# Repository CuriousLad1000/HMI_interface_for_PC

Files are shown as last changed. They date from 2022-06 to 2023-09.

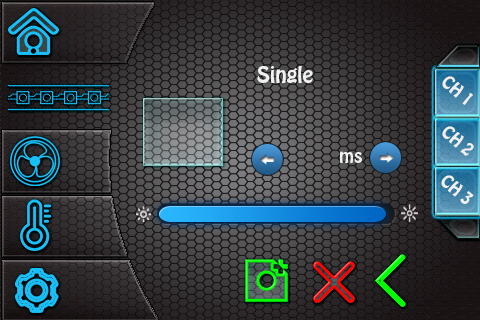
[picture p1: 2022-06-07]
UI Design files/LED/Single_Glow.png

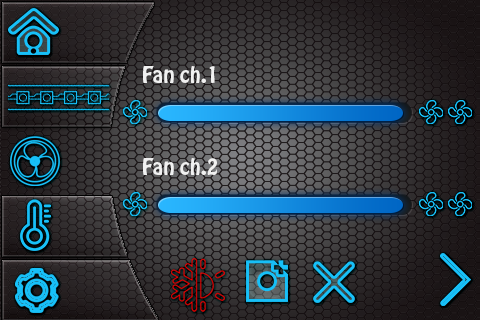
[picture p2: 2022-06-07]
UI Design files/FAN/Fan.png

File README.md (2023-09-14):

# HMI interface for PC

## Introduction

Personal Computers have become an integral part of our lives that even thinking about living without one would give us the feeling of falling back into stone age.

The idea behind this project was to build a smart Human Machine Interface for my personal computer. This project provided me with the opportunity of honing my skills while exploring various other domains. This project required technical expertise from different fields of technology including Electronics, Computer Science and Mechanical.

## Project Objective

The HMI interface will provide some advanced functionalities such as auto boot and shutdown, Automatic Temperature controller, vent controller, Lighting controller etc…

The project will involve some custom hardware designing, PCB fabrication, UX Designing, firmware programming, some mechanical designing and assembly using Rapid prototyping machines.

## Hardware/components used (not exhaustive list)

-   Arduino MEGA
-   3.5-inch Touch panel from Nextion
-   DC to DC Buck-Boost drivers
-   Mosfets (IRF510)
-   various passive components
-   Acryllic and MDF for casing and PC cabinet casing.
-   Laser cutter
-   CNC milling machine

## Software used

-   Arduino IDE (C/C++)
-   Nextion Editor to program touch panel.
-   Adobe Photoshop for UI designing.
-   Corel draw for Case, side panel and vents designing.
-   Cadsoft Eagle for PCB designing
-   Roland’s software and artcam for PCB fabrication (CNC milling).

##  Features offered

After completion, the HMI interface will have the following features.

-   Provide interactive system on/off switch
-   System Power on scheduler
-   Control the speed of fan based on conditions set.
    -   manual control of fan speed
    -   Automatic control based on the component’s temperature
-   Different Lighting modes for the system across multiple channels
    -   Rainbow
    -   Single color
    -   Fading on single color
    -   Rainbow cycle
    -   Color based on temperature
-   Display current temperature on multiple temperature gauges.
-   Provide settings for additional functionalities such as
    -   Open vents when system boots or based on the temperature -- servo control
    -   Enable power saver
    -   Enable/disable system status LED.
    -   Temperature channel assignment to various components.

<br/>

## Sample pictures (refer to wiki for more…)

<br/>

### HMI Interface

<br/>

**Home screen**

<p align="Center">
  
</p>

<p align="Center"> <i>"note: logo copyright belongs to Micro-Star INT'L CO., LTD" </i></p>

<br/>
<br/>

**Set Lighting modes**

<p align="Center">
  
</p>

<br/>
<br/>

**Temperature monitor**

<p align="Center">
  
</p>

<br/>
<br/>

## Device pics

<p align="Center">
  
</p>

<br/>
<br/>

**HMI Installed**

<p align="Center">
  
</p>

<br/>
<br/>

**HMI Operational**

<p align="Center">
  
</p>

<br/>
<br/>

> Check out wiki for more pics

<br/>
<br/>

### Video

<br/>
<br/>

**Device in action part-1**

<p align="Center">
  
</p>

<br/>
<br/>

**Device in action part-2**

<p align="Center">
  
</p>

<br/>

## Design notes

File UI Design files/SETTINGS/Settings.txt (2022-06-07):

setting for date and time

Open flaps when system boots  -- servo control

* flaps based on temperature -- Test basis

Enable power saver screen

Enable/disable system status LED. (Blue light on CPU cabinet)

Reset nextion display

-assign channels in settings to

-Controller
-CPU
-GPU
-HDD

-GPU
-HDD
-HDD Bay
-Motherboard

-HDD Bay
-Motherboard
-N-Bridge
-PSU

-N-Bridge
-PSU
-Radiator
-RAM

-PSU
-Radiator
-RAM
-Reservoir

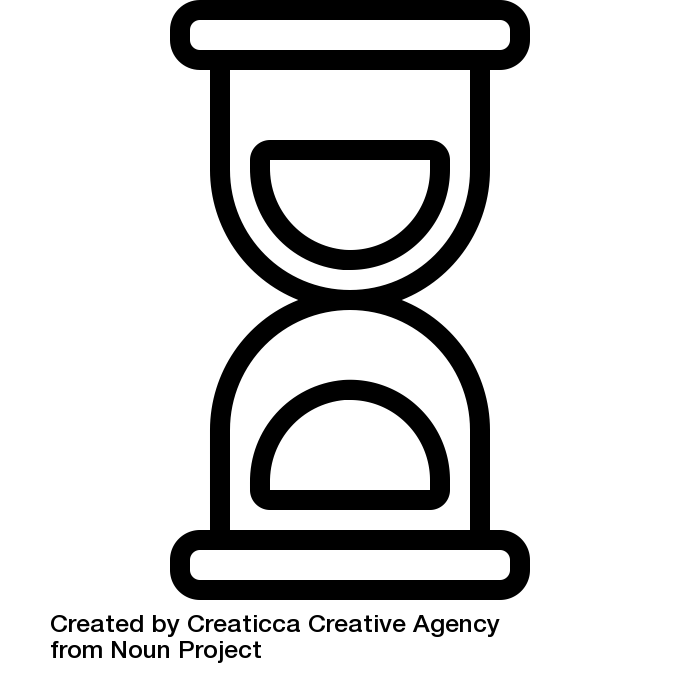
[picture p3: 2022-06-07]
UI Design files/HOME/noun_965902_cc.png

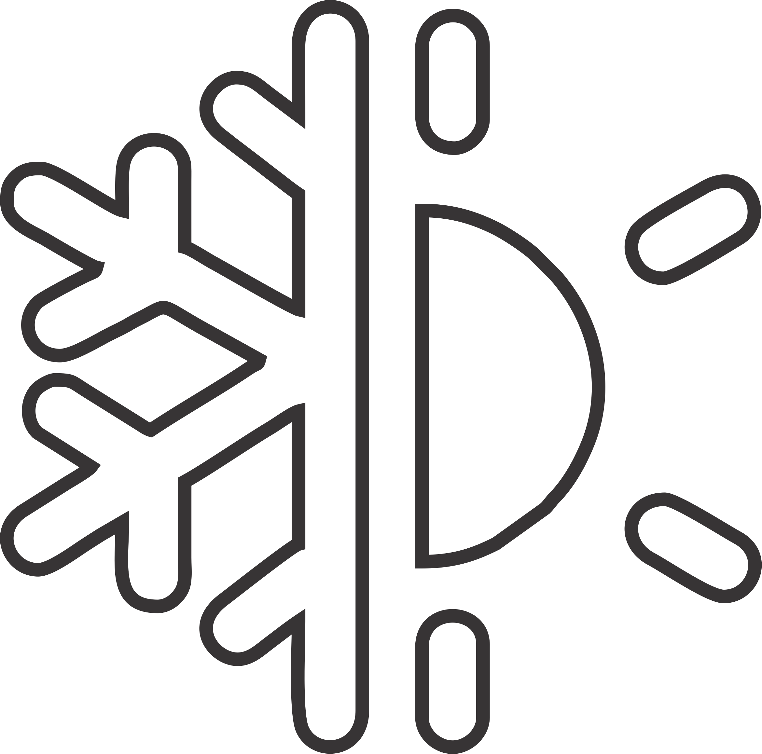
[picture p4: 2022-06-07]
UI Design files/FAN/tst2.png

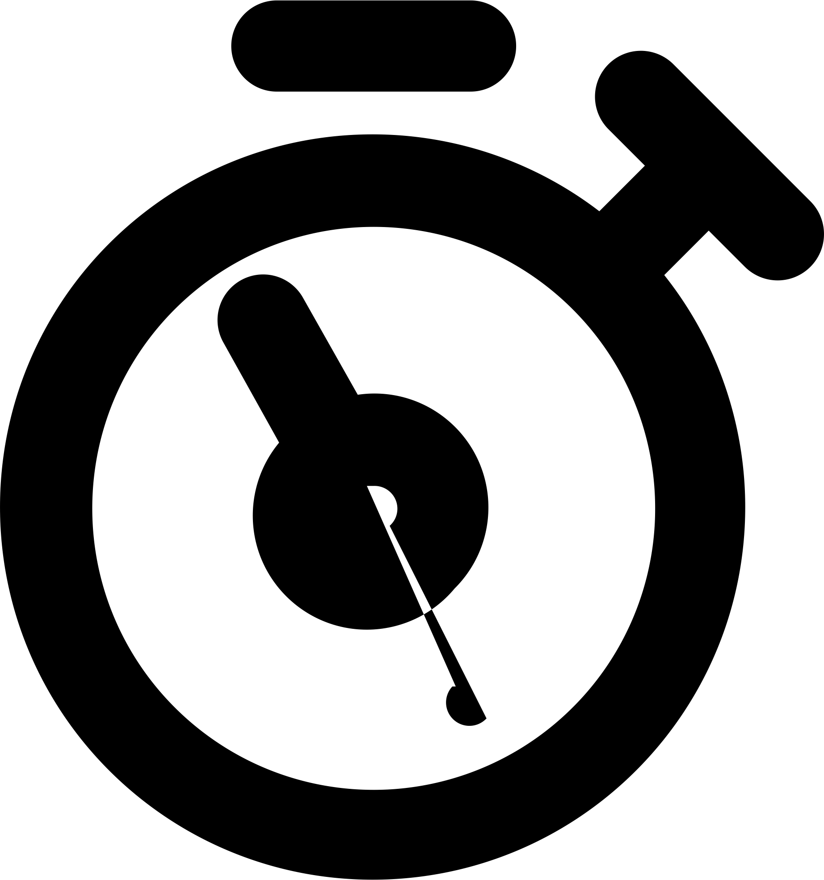
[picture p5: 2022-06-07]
UI Design files/HOME/Untitled-1.png

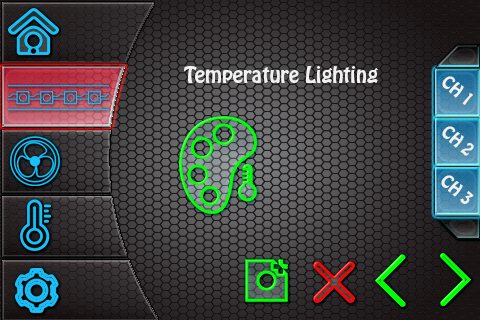
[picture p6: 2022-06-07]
UI Design files/LED/TempLight_Glow.png

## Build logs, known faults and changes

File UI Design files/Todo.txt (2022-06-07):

tst and prepare code for leds   --------------------- done

verify working of servo motor code    --------------- done

complie and run final test for the code  --------- done

add blink logo when shutdown command initiates

add power saver from nextion library and test it.  ----- done

create power switch jumper splitter  -- done

create connector harness for fans and LEDs

prepare sensors for installation

assemble servo vents and test it

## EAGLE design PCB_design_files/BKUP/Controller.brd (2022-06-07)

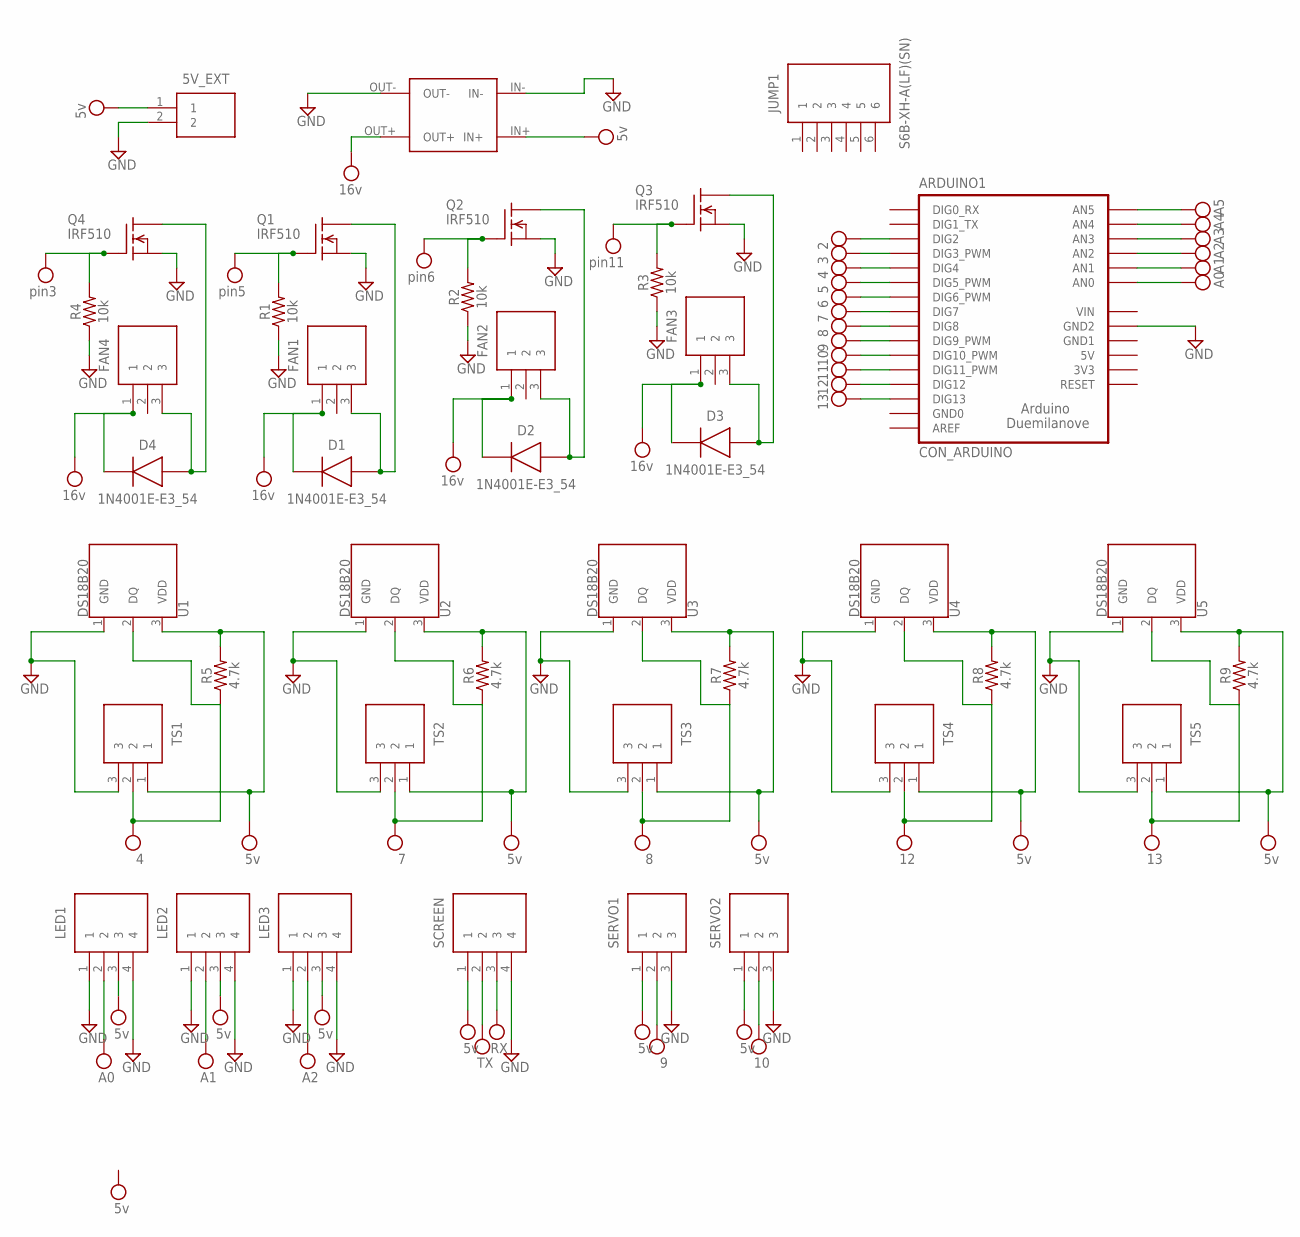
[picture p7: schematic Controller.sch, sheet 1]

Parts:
5V_EXT: S2B-XH-A(LF)(SN); SHDR2W80P0X250_1X2_740X575X700
ARDUINO1: CON_ARDUINO
D1, D2, D3, D4: 1N4001E-E3_54; DIOAD1405W86L465D235
FAN1, FAN2, FAN3, FAN4: S3B-XH-A(LF)(SN); SHDR3W80P0X250_1X3_990X610X700
JUMP1: S6B-XH-A(LF)(SN); SHDR6W64P0X250_1X6_1740X1155X7
LED1, LED2, LED3: S4B-XH-A(LF)(SN); SHDR4W64P0X250_1X4_1240X1155X7
Q1, Q2, Q3, Q4: IRF510; TO220
R1, R2, R3, R4: 10k; AXIAL-0.3
R5, R6, R7, R8, R9: 4.7k; AXIAL-0.3
SCREEN: S4B-XH-A(LF)(SN); SHDR4W64P0X250_1X4_1240X1155X7
SERVO1, SERVO2: S3B-XH-A(LF)(SN); SHDR3W80P0X250_1X3_990X610X700
TS1, TS2, TS3, TS4, TS5: S3B-XH-A(LF)(SN); SHDR3W80P0X250_1X3_990X610X700
U1, U2, U3, U4, U5: DS18B20; TO-92-AMMO
U$1: CN6009THROUGH_HOLE; CN6009

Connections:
5V_EXT: 5V_EXT.1, LED1.3, LED2.3, LED3.3, R5.P$2 (2), R6.P$2 (2), R7.P$2 (2), R8.P$2 (2), R9.P$2 (2), SCREEN.1, SERVO1.1, SERVO2.1, TS1.1, TS2.1, TS3.1, TS4.1, TS5.1, U1.3 (VDD), U2.3 (VDD), U3.3 (VDD), U4.3 (VDD), U5.3 (VDD), U$1.IN+; also elsewhere on the board
16V: D1.2 (K), D2.2 (K), D3.2 (K), D4.2 (K), FAN1.1, FAN2.1, FAN3.1, FAN4.1, U$1.OUT+; also elsewhere on the board
GND: 5V_EXT.2, ARDUINO1.GND2, LED1.1, LED1.4, LED2.1, LED2.4, LED3.1, LED3.4, Q1.3 (S), Q2.3 (S), Q3.3 (S), Q4.3 (S), R1.P$1 (1), R2.P$1 (1), R3.P$1 (1), R4.P$1 (1), SCREEN.4, SERVO1.3, SERVO2.3, TS1.3, TS2.3, TS3.3, TS4.3, TS5.3, U1.1 (GND), U2.1 (GND), U3.1 (GND), U4.1 (GND), U5.1 (GND), U$1.IN-, U$1.OUT-; also elsewhere on the board
unnamed: D2.1 (A), FAN2.3, Q2.2 (D)
unnamed: D3.1 (A), FAN3.3, Q3.2 (D)
unnamed: D1.1 (A), FAN1.3, Q1.2 (D)
unnamed: D4.1 (A), FAN4.3, Q4.2 (D)
PIN2: ARDUINO1.D_2 (DIG2)
PIN3: ARDUINO1.D_3 (DIG3_PWM), Q4.1 (G), R4.P$2 (2); also elsewhere on the board
PIN4: ARDUINO1.D_4 (DIG4), R5.P$1 (1), TS1.2, U1.2 (DQ)
PIN5: ARDUINO1.D_5 (DIG5_PWM), Q1.1 (G), R1.P$2 (2); also elsewhere on the board
PIN6: ARDUINO1.D_6 (DIG6_PWM), Q2.1 (G), R2.P$2 (2); also elsewhere on the board
PIN7: ARDUINO1.D_7 (DIG7), R6.P$1 (1), TS2.2, U2.2 (DQ)
PIN8: ARDUINO1.D_8 (DIG8), R7.P$1 (1), TS3.2, U3.2 (DQ)
PIN9: ARDUINO1.D_9 (DIG9_PWM), SERVO1.2
PIN10: ARDUINO1.D_10 (DIG10_PWM), SERVO2.2
PIN11: ARDUINO1.D_11 (DIG11_PWM), Q3.1 (G), R3.P$2 (2); also elsewhere on the board
PIN12: ARDUINO1.D_12 (DIG12), R8.P$1 (1), TS4.2, U4.2 (DQ)
PIN13: ARDUINO1.D_13 (DIG13), R9.P$1 (1), TS5.2, U5.2 (DQ)
PIN_A0: ARDUINO1.A_0 (AN0), LED1.2
PIN_A1: ARDUINO1.A_1 (AN1), LED2.2
PIN_A2: ARDUINO1.A_2 (AN2), LED3.2
PIN_A3: ARDUINO1.A_3 (AN3), SCREEN.2
PIN_A4: ARDUINO1.A_4 (AN4), SCREEN.3
PIN_A5: ARDUINO1.A_5 (AN5)
VIN: ARDUINO1.VIN

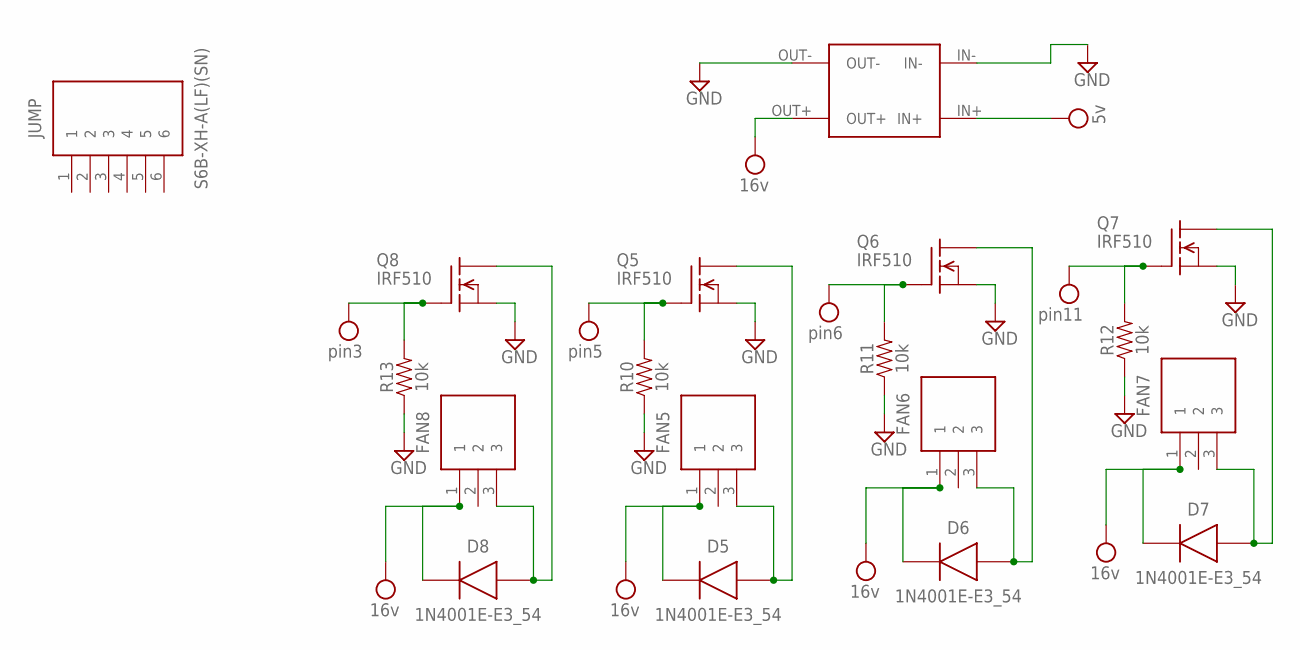
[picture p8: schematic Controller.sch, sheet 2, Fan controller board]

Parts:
D5, D6, D7, D8: 1N4001E-E3_54; DIOAD1405W86L465D235
FAN5, FAN6, FAN7, FAN8: S3B-XH-A(LF)(SN); SHDR3W80P0X250_1X3_990X610X700
JUMP: S6B-XH-A(LF)(SN); SHDR6W64P0X250_1X6_1740X1155X7
Q5, Q6, Q7, Q8: IRF510; TO220
R10, R11, R12, R13: 10k; AXIAL-0.3
U$2: CN6009THROUGH_HOLE; CN6009

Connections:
5V_EXT: U$2.IN+; also elsewhere on the board
16V: D5.2 (K), D6.2 (K), D7.2 (K), D8.2 (K), FAN5.1, FAN6.1, FAN7.1, FAN8.1, U$2.OUT+; also elsewhere on the board
GND: Q5.3 (S), Q6.3 (S), Q7.3 (S), Q8.3 (S), R10.P$1 (1), R11.P$1 (1), R12.P$1 (1), R13.P$1 (1), U$2.IN-, U$2.OUT-; also elsewhere on the board
unnamed: D5.1 (A), FAN5.3, Q5.2 (D)
unnamed: D6.1 (A), FAN6.3, Q6.2 (D)
unnamed: D7.1 (A), FAN7.3, Q7.2 (D)
unnamed: D8.1 (A), FAN8.3, Q8.2 (D)
PIN3: Q8.1 (G), R13.P$2 (2); also elsewhere on the board
PIN5: Q5.1 (G), R10.P$2 (2); also elsewhere on the board
PIN6: Q6.1 (G), R11.P$2 (2); also elsewhere on the board
PIN11: Q7.1 (G), R12.P$2 (2); also elsewhere on the board

Board: 2 copper layers, 59 parts (0 on the bottom side), 27 nets, no tracks yet.

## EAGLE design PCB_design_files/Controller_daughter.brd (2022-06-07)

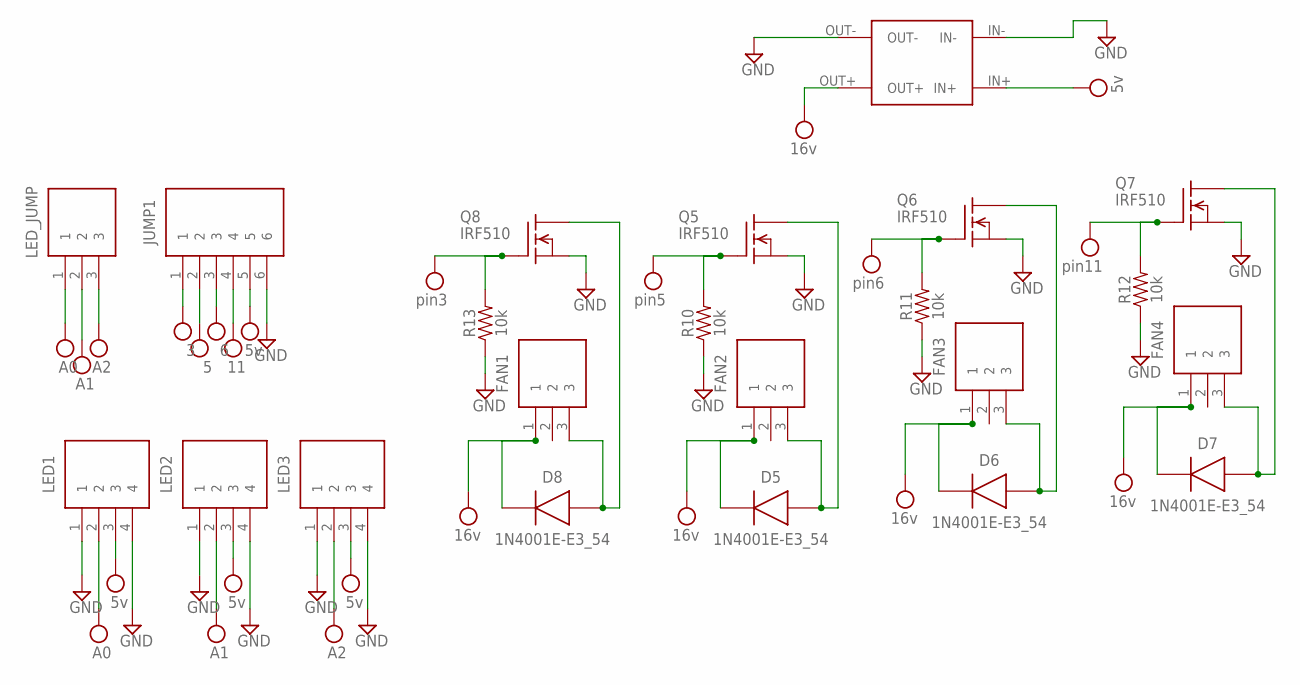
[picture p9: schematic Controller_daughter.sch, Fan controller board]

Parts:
D5, D6, D7, D8: 1N4001E-E3_54; DIOAD1405W86L465D235
FAN1, FAN2, FAN3, FAN4: S3B-XH-A(LF)(SN); SHDR3W80P0X250_1X3_990X610X700
JUMP1: S6B-XH-A(LF)(SN); SHDR6W64P0X250_1X6_1740X1155X7
LED1, LED2, LED3: S4B-XH-A(LF)(SN); SHDR4W64P0X250_1X4_1240X1155X7
LED_JUMP: S3B-XH-A(LF)(SN); SHDR3W80P0X250_1X3_990X610X700
Q5, Q6, Q7, Q8: IRF510; TO220
R10, R11, R12, R13: 10k; AXIAL-0.3
U$2: CN6009THROUGH_HOLE; CN6009

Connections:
5V_EXT: JUMP1.5, LED1.3, LED2.3, LED3.3, U$2.IN+
16V: D5.2 (K), D6.2 (K), D7.2 (K), D8.2 (K), FAN1.1, FAN2.1, FAN3.1, FAN4.1, U$2.OUT+
GND: JUMP1.6, LED1.1, LED1.4, LED2.1, LED2.4, LED3.1, LED3.4, U$2.IN-
GND_16: Q5.3 (S), Q6.3 (S), Q7.3 (S), Q8.3 (S), R10.P$1 (1), R11.P$1 (1), R12.P$1 (1), R13.P$1 (1), U$2.OUT-
unnamed: D5.1 (A), FAN2.3, Q5.2 (D)
unnamed: D6.1 (A), FAN3.3, Q6.2 (D)
unnamed: D7.1 (A), FAN4.3, Q7.2 (D)
unnamed: D8.1 (A), FAN1.3, Q8.2 (D)
PIN3: JUMP1.1, Q8.1 (G), R13.P$2 (2)
PIN5: JUMP1.2, Q5.1 (G), R10.P$2 (2)
PIN6: JUMP1.3, Q6.1 (G), R11.P$2 (2)
PIN11: JUMP1.4, Q7.1 (G), R12.P$2 (2)
PIN_A0: LED1.2, LED_JUMP.1
PIN_A1: LED2.2, LED_JUMP.2
PIN_A2: LED3.2, LED_JUMP.3

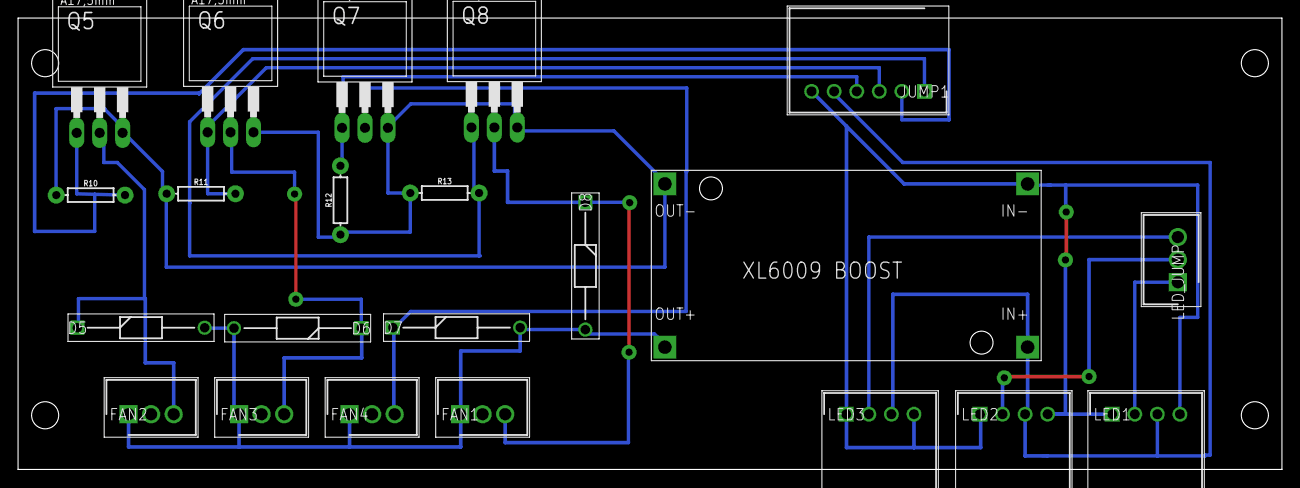
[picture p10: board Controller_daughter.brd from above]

Board: 2 copper layers, 140.0 x 50.0 mm, 22 parts (0 on the bottom side), 15 nets.

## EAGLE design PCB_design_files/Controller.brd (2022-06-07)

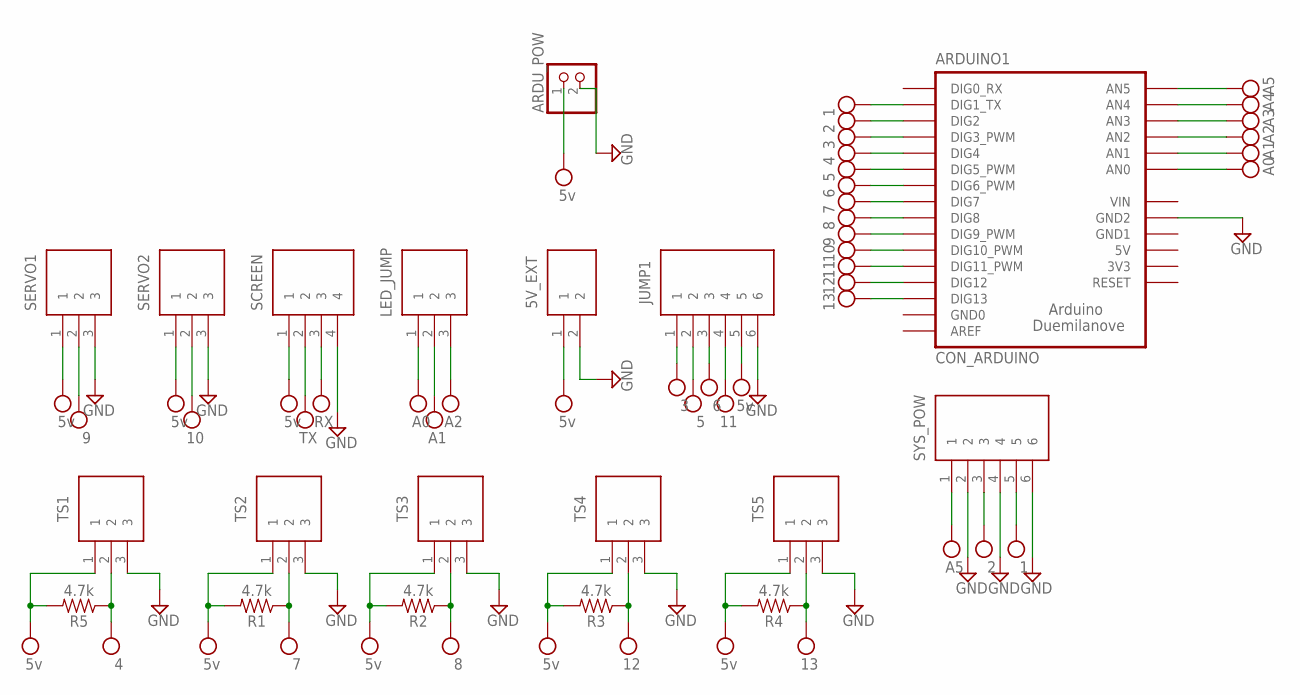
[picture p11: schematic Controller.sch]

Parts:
5V_EXT: S2B-XH-A(LF)(SN); SHDR2W80P0X250_1X2_740X575X700
ARDUINO1: CON_ARDUINO
ARDU_POW: PINHD-1X2; 1X02
JUMP1: S6B-XH-A(LF)(SN); SHDR6W64P0X250_1X6_1740X1155X7
LED_JUMP: S3B-XH-A(LF)(SN); SHDR3W80P0X250_1X3_990X610X700
R1, R2, R3, R4, R5: 4.7k; AXIAL-0.3
SCREEN: S4B-XH-A(LF)(SN); SHDR4W64P0X250_1X4_1240X1155X7
SERVO1, SERVO2: S3B-XH-A(LF)(SN); SHDR3W80P0X250_1X3_990X610X700
SYS_POW: S6B-XH-A(LF)(SN); SHDR6W64P0X250_1X6_1740X1155X7
TS1, TS2, TS3, TS4, TS5: S3B-XH-A(LF)(SN); SHDR3W80P0X250_1X3_990X610X700

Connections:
5V_EXT: 5V_EXT.1, ARDU_POW.1, JUMP1.5, R1.P$2 (2), R2.P$2 (2), R3.P$2 (2), R4.P$2 (2), R5.P$2 (2), SCREEN.1, SERVO1.1, SERVO2.1, TS1.1, TS2.1, TS3.1, TS4.1, TS5.1
GND: 5V_EXT.2, ARDUINO1.GND2, ARDU_POW.2, JUMP1.6, SCREEN.4, SERVO1.3, SERVO2.3, SYS_POW.2, SYS_POW.4, SYS_POW.6, TS1.3, TS2.3, TS3.3, TS4.3, TS5.3
PIN1: ARDUINO1.D_1 (DIG1_TX), SYS_POW.5
PIN2: ARDUINO1.D_2 (DIG2), SYS_POW.3
PIN3: ARDUINO1.D_3 (DIG3_PWM), JUMP1.1
PIN4: ARDUINO1.D_4 (DIG4), R5.P$1 (1), TS1.2
PIN5: ARDUINO1.D_5 (DIG5_PWM), JUMP1.2
PIN6: ARDUINO1.D_6 (DIG6_PWM), JUMP1.3
PIN7: ARDUINO1.D_7 (DIG7), R1.P$1 (1), TS2.2
PIN8: ARDUINO1.D_8 (DIG8), R2.P$1 (1), TS3.2
PIN9: ARDUINO1.D_9 (DIG9_PWM), SERVO1.2
PIN10: ARDUINO1.D_10 (DIG10_PWM), SERVO2.2
PIN11: ARDUINO1.D_11 (DIG11_PWM), JUMP1.4
PIN12: ARDUINO1.D_12 (DIG12), R3.P$1 (1), TS4.2
PIN13: ARDUINO1.D_13 (DIG13), R4.P$1 (1), TS5.2
PIN_A0: ARDUINO1.A_0 (AN0), LED_JUMP.1
PIN_A1: ARDUINO1.A_1 (AN1), LED_JUMP.2
PIN_A2: ARDUINO1.A_2 (AN2), LED_JUMP.3
PIN_A3: ARDUINO1.A_3 (AN3), SCREEN.2
PIN_A4: ARDUINO1.A_4 (AN4), SCREEN.3
PIN_A5: ARDUINO1.A_5 (AN5), SYS_POW.1
VIN: ARDUINO1.VIN

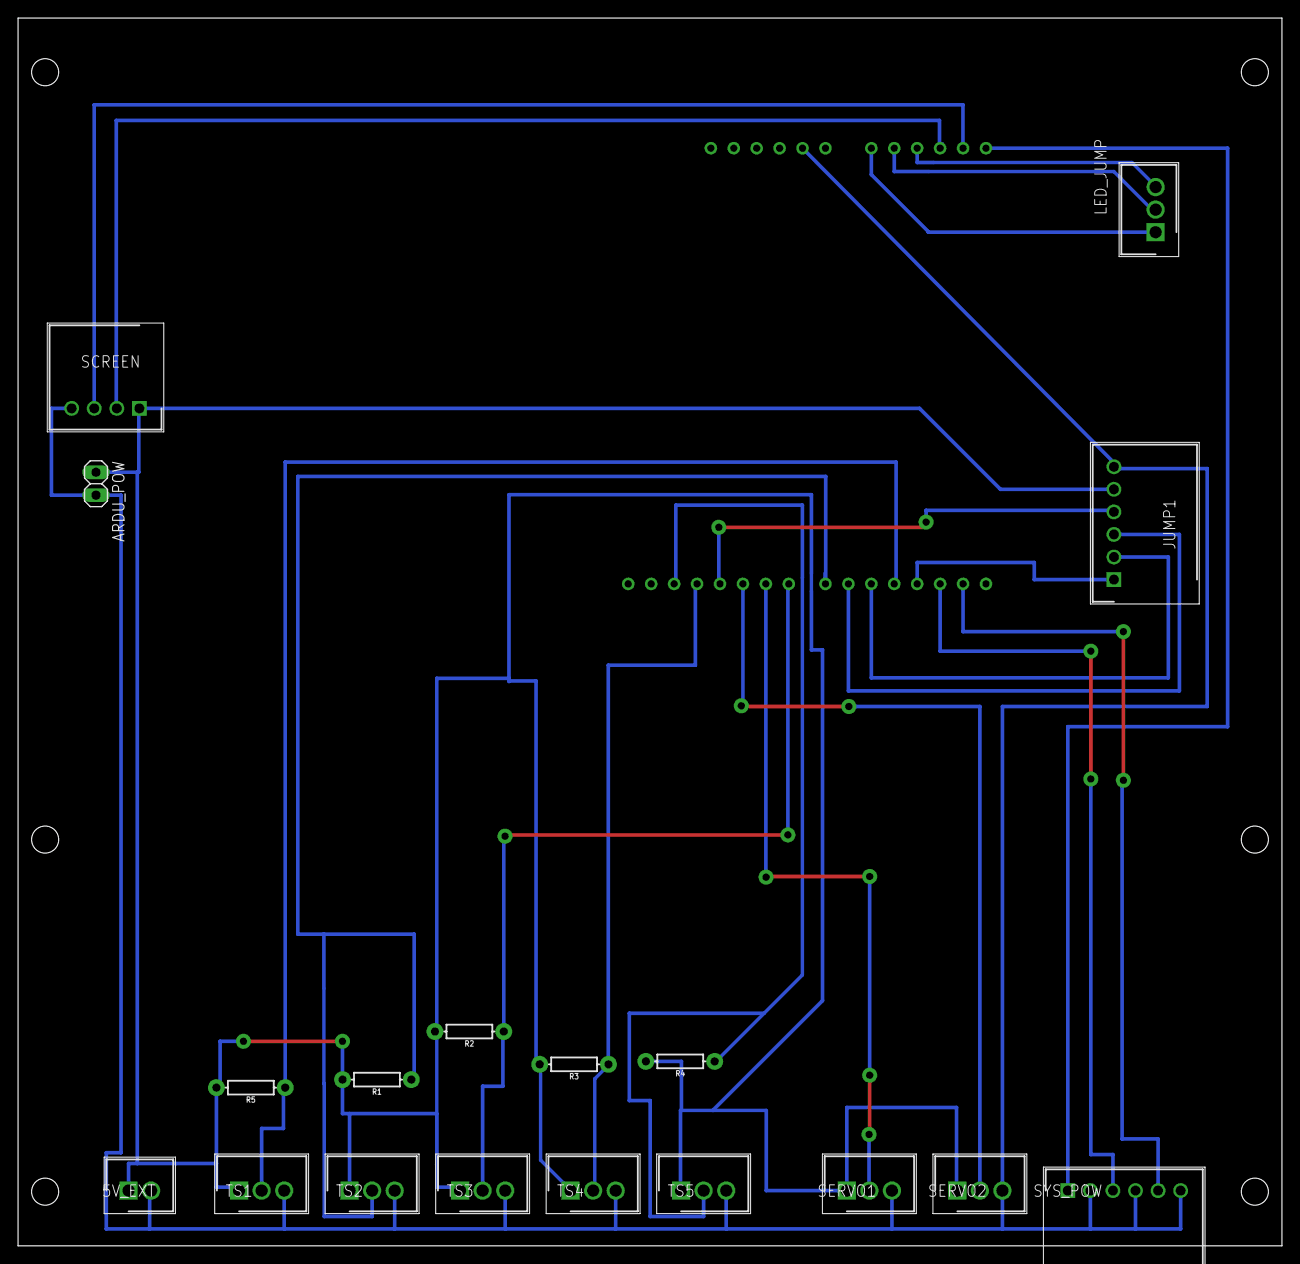
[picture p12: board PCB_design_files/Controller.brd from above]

Board: 2 copper layers, 140.0 x 136.0 mm, 19 parts (1 on the bottom side), 21 nets.

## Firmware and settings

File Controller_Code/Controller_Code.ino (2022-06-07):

#include <SoftwareSerial.h>
#include <Nextion.h>
#include <OneWire.h>
#include <DallasTemperature.h>
#include "FastLED.h"
#include <Servo.h>
//===============================  PIN MAPPING ======================================================
//=================== POW BUTTON =============================
int sys_pow_pin = A5;  // CPU ON/OFF switch pin
int sys_led_pin = 1;  // CPU LED
int sys_stat_pin = 2; // input to detect PC status

//================= LED ========================
#define LED_CH1  A0
#define LED_CH2  A1
#define LED_CH3  A2
#define NUM_LEDS 32     // # of LEDS in the strip
CRGB leds_CH1[NUM_LEDS];
CRGB leds_CH2[NUM_LEDS];
CRGB leds_CH3[NUM_LEDS];
CRGBPalette16 Single_Fade = Nextion1_gp;
CRGBPalette16 myPal = temperature_gp;
CRGBPalette16 RBW = Rainbow_gp;
//================= FAN ========================
int FAN_CH1 = 3;
int FAN_CH2 = 5;
int FAN_CH3 = 6;
int FAN_CH4 = 11;

//======================== Temperature Sensors=========================================
int CH1_TMP = 4;
OneWire oneWire1(CH1_TMP);
DallasTemperature sensors1(&oneWire1);
//===================== DS18b20(CH2_TMP) ========================
int CH2_TMP = 7;
OneWire oneWire2(CH2_TMP);
DallasTemperature sensors2(&oneWire2);
//===================== DS18b20(CH3_TMP) ========================
int CH3_TMP = 8;
OneWire oneWire3(CH3_TMP);
DallasTemperature sensors3(&oneWire3);
//===================== DS18b20(CH4_TMP) ========================
int CH4_TMP = 12;
OneWire oneWire4(CH4_TMP);
DallasTemperature sensors4(&oneWire4);
//===================== DS18b20(CH5_TMP) ========================
int CH5_TMP = 13;
OneWire oneWire5(CH5_TMP);
DallasTemperature sensors5(&oneWire5);
//===========================SERVO PIN===========================================
Servo myservo;
int sv1 = 9;
int sv2 = 10;

//========================= LCD =============================================
int LCD_TX = A8;  // A8 ON MEGA ROUTED TO A3
int LCD_RX = A4;
SoftwareSerial nextion(LCD_TX, LCD_RX);
Nextion myNextion(nextion, 9600); //create a Nextion object named myNextion using the nextion serial port @ 9600bps



//============================SYS POW var.============================================
int sys_stat;
int sys_stat2;
int sys_led;
int sys_switch_prev = 0;
int sys_switch;

//========================== FAN ==============================================
String loc1 = "FAN.fanSli1";
String loc2 = "FAN.fanSli2";
String loc3 = "FAN2.fanSli3";
String loc4 = "FAN2.fanSli4";
int ch1_SLI;
int ch2_SLI;
int ch3_SLI;
int ch4_SLI;
int auto_tmp;
int Res_Temp;   //for auto fan control
int FAN;
//========================== LED Var ==============================================

byte S_cntr;
byte S_sli1;
int S_del1;
byte chnl1;
byte chnl2;
byte chnl3;
byte F_cntr;
byte F_sli1;
int F_del1;
byte R_sli1;
int R_del1;
byte R_sli2;
int R_del2;
byte Tclr;
int clr_Temp;
int LED;
//============================SERVO var.=================================
int flag_on = 0;
int flag_off = 0;
int pos;
int pos_auto;
int flap_boot;
int flap_heat;
//=========================================================================

void setup()
{
  //Serial.begin(9600);

  sensors1.begin();  // for ds18b20
  sensors2.begin();  // for ds18b20
  sensors3.begin();  // for ds18b20
  sensors4.begin();  // for ds18b20
  sensors5.begin();  // for ds18b20

  FastLED.addLeds<NEOPIXEL, LED_CH1>(leds_CH1, NUM_LEDS); // for fastLED ch1
  FastLED.addLeds<NEOPIXEL, LED_CH2>(leds_CH2, NUM_LEDS); // for fastLED ch2
  FastLED.addLeds<NEOPIXEL, LED_CH3>(leds_CH3, NUM_LEDS); // for fastLED ch3

  pinMode(sys_pow_pin, OUTPUT);
  digitalWrite(sys_pow_pin, HIGH);
  pinMode(sys_led_pin, OUTPUT);
  pinMode(sys_stat_pin, INPUT);

  pinMode(FAN_CH1, OUTPUT);
  pinMode(FAN_CH2, OUTPUT);
  pinMode(FAN_CH3, OUTPUT);
  pinMode(FAN_CH4, OUTPUT);
  myNextion.init();

  myservo.attach(sv1);
  //myservo.attach(sv2);
}
void loop()
{
  ch1_SLI = myNextion.getComponentValue("FAN.fanSli1");  // 0 to 100 values
  ch2_SLI = myNextion.getComponentValue("FAN.fanSli2"); // 0 to 100 values
  ch3_SLI = myNextion.getComponentValue("FAN2.fanSli3"); // 0 to 100 values
  ch4_SLI = myNextion.getComponentValue("FAN2.fanSli4"); // 0 to 100 values
  auto_tmp = myNextion.getComponentValue("FAN.auto"); // 0 or 1 value
  FAN = myNextion.getComponentValue("SET2.FAN"); // 0 or 1 value

  S_cntr = myNextion.getComponentValue("SINGLE.cntr_0"); // 1 to 16 values
  S_sli1 = myNextion.getComponentValue("SINGLE.Ssli1_0"); // 0 to 100 values
  S_del1 = myNextion.getComponentValue("SINGLE.Sdel1_0"); // 10 to 1000 values
  chnl1 = myNextion.getComponentValue("SINGLE.chnl1"); // 1 to 6 values
  chnl2 = myNextion.getComponentValue("SINGLE.chnl2"); // 1 to 6 values
  chnl3 = myNextion.getComponentValue("SINGLE.chnl3"); // 1 to 6 values
  F_cntr = myNextion.getComponentValue("FADE.cntr_0"); // 1 to 16 values
  F_sli1 = myNextion.getComponentValue("FADE.Fsli1_0"); // 0 to 100 values
  F_del1 = myNextion.getComponentValue("FADE.Fdel1_0"); // 10 to 1000 values
  R_sli1 = myNextion.getComponentValue("RAINBOW.Rsli1_0"); // 0 to 100 values
  R_del1 = myNextion.getComponentValue("RAINBOW.Rdel1_0"); // 10 to 1000 values
  R_sli2 = myNextion.getComponentValue("RAINBOW2.Rsli2_0"); // 0 to 100 values
  R_del2 = myNextion.getComponentValue("RAINBOW2.Rdel2_0"); // 10 to 1000 values
  Tclr = myNextion.getComponentValue("AUTOCLR.Tclr_0"); // 0 or 1 values
  LED = myNextion.getComponentValue("SET2.LED"); // 0 or 1 value

  // Serial.println(F_sli1);
  // Serial.println(F_del1);
  // Serial.println(chnl1);

  sys_switch = myNextion.getComponentValue("HOME.n0"); // 0 or 1 value
  sys_led = myNextion.getComponentValue("SET1.sys_led"); // 0 or 1 value

  flap_boot = myNextion.getComponentValue("SET1.flapBoot"); // 0 or 1 value
  flap_heat = myNextion.getComponentValue("SET1.flapHeat"); // 0 or 1 value

  S_cntr = constrain(S_cntr, 1, 16);
  S_sli1 = constrain(S_sli1, 0, 100);
  S_del1 = constrain(S_del1, 10, 1000);
  chnl1 = constrain(chnl1, 1, 6);
  chnl2 = constrain(chnl2, 1, 6);
  chnl3 = constrain(chnl3, 1, 6);
  F_cntr = constrain(F_cntr, 1, 16);
  F_sli1 = constrain(F_sli1, 0, 100);
  F_del1 = constrain(F_del1, 10, 1000);
  R_sli1 = constrain(R_sli1, 0, 100);
  R_del1 = constrain(R_del1, 10, 1000);
  R_sli2 = constrain(R_sli2, 0, 100);
  R_del2 = constrain(R_del2, 10, 1000);
  Tclr = constrain(Tclr, 0, 1);
  // Serial.print("FAN: ");
  // Serial.println(FAN);


  //===============================  Temperature CODE  ===================================================================

  Res_Temp = TempSys_TX(sensors1, 1);  // (Sensor number; channel number)
  //  Res_Temp = 50;
  Res_Temp = constrain(Res_Temp, 0, 70); // fan at full speed if temp. hits 70;
  clr_Temp = Res_Temp;
  // Serial.println(Res_Temp);
  int Res_Temp2 = TempSys_TX(sensors2, 2);
  Res_Temp2 = TempSys_TX(sensors3, 3);
  Res_Temp2 = TempSys_TX(sensors4, 4);
  Res_Temp2 = TempSys_TX(sensors5, 5);
  //=========================================SYSTEM POWER CODE==========================================================
  //=== Detect Button Press ==

  if (sys_switch == -1)
  {
  }
  else
  {
    //Serial.print("sys_switch: ");
    //Serial.println(sys_switch);
    if (sys_switch != sys_switch_prev)
    {
      if (sys_stat == 0)
      {
        //Serial.println("Firing UP the PC");
        sys_stat = 1;
        sys_pow(); // SEND SIGNAL TO BOOT PC
      }
      else if (sys_stat == 1)
      {
        //Serial.println("Shutting Down PC");
        sys_stat = 0;
        sys_pow();// SEND SIGNAL TO SHUTDOWN PC
      }
    }
    sys_switch_prev = sys_switch;
  }
  sys_status();

  //============================= This code is changing the front pic of button========================================
  if (sys_stat2 == 1)
  {
    myNextion.sendCommand("HOME.ON.picc=5");  // changes picc
  }

  else if (sys_stat2 == 0)
  {
    myNextion.sendCommand("HOME.ON.picc=0");
  }
  //Serial.println();
  //=================================== System LED status =======================
  system_LED();

  //=================================== SERVO FLAP ==============================================
  // Serial.print("sys stat: ");
  // Serial.println(sys_stat2);
  // Serial.print("flag_on: ");
  // Serial.println(flag_on);
  // Serial.print("flag_off: ");
  // Serial.println(flag_off);
  if (flap_boot == 1 && flap_heat == 0)
  {
    srvo();
  }
  else if (flap_heat == 1 && sys_stat2 == 1 && flap_boot == 0)
  {
    srvo_auto();
  }
  else if ((flap_boot == 0 && flap_heat == 0) || (flap_boot == 1 && flap_heat == 1))
  {
    // Do nothing
  }
  // myservo.detach();
  //=========================================================================================== Fan Auto =============
  //  Serial.print("system_stat: ");
  //  Serial.println(sys_stat2);
  //  Serial.print("FAN: ");
  //  Serial.println(FAN);

  if (FAN == 1)
  {
    if (sys_stat2 == 1)
    {
      if (auto_tmp == 1)
      {
        MAP_FAN_AUTO(FAN_CH1, loc1);
        MAP_FAN_AUTO(FAN_CH2, loc2);
        MAP_FAN_AUTO(FAN_CH3, loc3);
        MAP_FAN_AUTO(FAN_CH4, loc4);
      }
      else if (auto_tmp == 0)
      {
        MAP_FAN(FAN_CH1, ch1_SLI);
        MAP_FAN(FAN_CH2, ch2_SLI);
        MAP_FAN(FAN_CH3, ch3_SLI);
        MAP_FAN(FAN_CH4, ch4_SLI);
      }
    }
    else if (sys_stat2 == 0)
    {
      analogWrite(FAN_CH1, 0); //0 and 40 to 255
      analogWrite(FAN_CH2, 0); //0 and 40 to 255
      analogWrite(FAN_CH3, 0); //0 and 40 to 255
      analogWrite(FAN_CH4, 0); //0 and 40 to 255
    }
  }
  else if (FAN == 0)
  {
    if (auto_tmp == 1)
    {
      MAP_FAN_AUTO(FAN_CH1, loc1);
      MAP_FAN_AUTO(FAN_CH2, loc2);
      MAP_FAN_AUTO(FAN_CH3, loc3);
      MAP_FAN_AUTO(FAN_CH4, loc4);
    }
    else if (auto_tmp == 0)
    {
      MAP_FAN(FAN_CH1, ch1_SLI);
      MAP_FAN(FAN_CH2, ch2_SLI);
      MAP_FAN(FAN_CH3, ch3_SLI);
      MAP_FAN(FAN_CH4, ch4_SLI);
    }
  }

  //=================================LED CODE=================================================================
  if (LED == 1)
  {

    if (sys_stat2 == 1)
    {
      led();
    }
    else
    {
      offline(1);
      offline(2);
      offline(3);
    }
  }
  else if (LED == 0)
  {
    led();
  }
}


//==================================================================================================================================================
//================================================================== FUNCTIONS =====================================================================
//==================================================================================================================================================
//=========================================SYSTEM FUNC.==========================================================
void system_LED()
{
  if (sys_stat2 == 1 && sys_led == 1)
  {
    digitalWrite(sys_led_pin, HIGH);
  }
  else
  {
    digitalWrite(sys_led_pin, LOW);
  }
}

void sys_status()
{
  if (digitalRead(sys_stat_pin) == HIGH)
  {
    sys_stat2 = 1;
  }
  else
  {
    sys_stat2 = 0;
  }
}

void sys_pow()
{
  digitalWrite(sys_pow_pin, LOW);
  delay(500);
  digitalWrite(sys_pow_pin, HIGH);
}


//=========================================== FAN ================================================
void MAP_FAN(int fan_ch, int ch_sli)
{
  if (ch_sli == 0)
  {
    analogWrite(fan_ch, 0); //0 and 40 to 255
  }
  else if (ch_sli > 0 && ch_sli < 16)
  {
    ch_sli = 40;
    analogWrite(fan_ch, ch_sli); //0 and 40 to 255
    //Serial.println(ch_sli);
  }
  else
  {
    ch_sli = map(ch_sli, 0, 100, 0, 255);
    // Serial.println(ch_sli);
    analogWrite(fan_ch, ch_sli); //0 and 40 to 255
  }
}


void MAP_FAN_AUTO(int fan_ch, String LOC)
{
  int value;
  if (Res_Temp > 0 && Res_Temp < 12)
  {
    value = 40;
    analogWrite(fan_ch, value);

    value = map(value, 0, 255, 0, 100);
    myNextion.setComponentValue(LOC, value);
  }
  else
  {
    value = map(Res_Temp, 0, 70, 0, 255);
    //Serial.println(value);
    analogWrite(fan_ch, value);

    value = map(value, 0, 255, 0, 100);
    myNextion.setComponentValue(LOC, value);
  }

}

//===========================================================  TEMPERATURE Func ====================================================
int TempSys_TX(DallasTemperature sensors, int ch_no)
{
  int Temp;
  sensors.requestTemperatures(); // Send the command to get temperatures
  float Res1 = sensors.getTempCByIndex(0);
  int Res1a = (int)Res1;
  String a =  (String(Res1) + "\xb0" + "C");  //xb0 is for degree symbol
  //  Serial.println(a);
  int scaled_value1 = map(Res1a, 0, 100, 0, 100); // always map value from 0 to 100
  if (ch_no == 1)
  {
    myNextion.setComponentText("TMP1.tmp0", a);
    myNextion.setComponentValue("TMP1.prg0", scaled_value1);
  }
  else if (ch_no == 2)
  {
    myNextion.setComponentText("TMP1.tmp1", a);
    myNextion.setComponentValue("TMP1.prg1", scaled_value1);
  }
  else if (ch_no == 3)
  {
    myNextion.setComponentText("TMP1.tmp2", a);
    myNextion.setComponentValue("TMP1.prg2", scaled_value1);
  }
  else if (ch_no == 4)
  {
    myNextion.setComponentText("TMP2.tmp3", a);
    myNextion.setComponentValue("TMP2.prg3", scaled_value1);
  }
  else if (ch_no == 5)
  {
    myNextion.setComponentText("TMP2.tmp4", a);
    myNextion.setComponentValue("TMP2.prg4", scaled_value1);
  }
  // Serial.println(a);
  Temp = Res1a;
  //Serial.println(Temp);
  return (Temp);
}

//================================================================== FOR LEDs ====================================================
void led()
{
  //=======================FOR CH1- modes =======================
  if (chnl1 == 5 || chnl2 == 5 || chnl3 == 5)
  {
    Temp_clr(clr_Temp);
  }
  else
  {
    switch (chnl1)
    {
      case 1: Single(S_cntr, S_sli1, 1, S_del1);
        break;
      case 2: Fade(F_cntr, F_sli1, 1, F_del1);
        break;
      case 3: Rainbow(R_sli1, 1, R_del1);
        break;
      case 4: Rainbow2(R_sli2, 1, R_del2);
        break;
      case 6: offline(1);
        break;
    }
    switch (chnl2)
    {
      case 1: Single(S_cntr, S_sli1, 2, S_del1);
        break;
      case 2: Fade(F_cntr, F_sli1, 2, F_del1);
        break;
      case 3: Rainbow(R_sli1, 2, R_del1);
        break;
      case 4: Rainbow2(R_sli2, 2, R_del2);
        break;
      case 6: offline(2);
        break;
    }
    switch (chnl3)
    {
      case 1: Single(S_cntr, S_sli1, 3, S_del1);
        break;
      case 2: Fade(F_cntr, F_sli1, 3, F_del1);
        break;
      case 3: Rainbow(R_sli1, 3, R_del1);
        break;
      case 4: Rainbow2(R_sli2, 3, R_del2);
        break;
      case 6: offline(3);
        break;
    }
  }
}

//================================================================== FOR SINGLE ====================================================
void Single(byte cntr, byte BRF, byte ch, int wait) // (S_cntr; S_sli1; Channel number; S_del1)
{
  BRF = BRF * 2.55;
  byte heatindex;
  heatindex = (16 * (cntr - 1));

  switch (ch)
  {
    case 1:
      {
        fill_palette( leds_CH1, NUM_LEDS, heatindex, 0, Single_Fade, BRF, LINEARBLEND);
        FastLED.show();
      }
      break;
    case 2:
      {
        fill_palette( leds_CH2, NUM_LEDS, heatindex, 0, Single_Fade, BRF, LINEARBLEND);
        FastLED.show();
      }
      break;
    case 3:
      {
        fill_palette( leds_CH3, NUM_LEDS, heatindex, 0, Single_Fade, BRF, LINEARBLEND);
        FastLED.show();
      }
      break;
  }
}
//======================================FADE============================================================================
void Fade(byte cntr, byte BRF, byte ch, int wait)
{
  byte heatindex;
  heatindex = (16 * (cntr - 1));
  byte light = BRF * 2.55;
  switch (ch)
  {
    case 1:
      {
        for (int i = 0; i < light; i++)
        {
          fill_palette( leds_CH1, NUM_LEDS, heatindex, 0, Single_Fade, i, LINEARBLEND);
          FastLED.show();
        }
        for (int i = light; i > 0; i--)
        {
          fill_palette( leds_CH1, NUM_LEDS, heatindex, 0, Single_Fade, i, LINEARBLEND);
          FastLED.show();
        }
        delay(wait);
      }
      break;
    case 2:
      {
        for (int i = 0; i < light; i++)
        {
          fill_palette( leds_CH2, NUM_LEDS, heatindex, 0, Single_Fade, i, LINEARBLEND);
          FastLED.show();
        }
        for (int i = light; i > 0; i--)
        {
          fill_palette( leds_CH2, NUM_LEDS, heatindex, 0, Single_Fade, i, LINEARBLEND);
          FastLED.show();
        }
        delay(wait);
      }
      break;
    case 3:
      {
        for (int i = 0; i < light; i++)
        {
          fill_palette( leds_CH3, NUM_LEDS, heatindex, 0, Single_Fade, i, LINEARBLEND);
          FastLED.show();
        }
        for (int i = light; i > 0; i--)
        {
          fill_palette( leds_CH3, NUM_LEDS, heatindex, 0, Single_Fade, i, LINEARBLEND);
          FastLED.show();
        }
        delay(wait);
      }
      break;
  }
}
//======================================================= FOR RAINBOW ===============================================================
void Rainbow(byte BRF, byte ch, int wait)
{
  static byte HI2;
  HI2 = HI2 + 1;
  BRF = BRF * 2.55;
  //Serial.println(HI2);
  switch (ch)
  {
    case 1:
      {
        fill_palette( leds_CH1, NUM_LEDS, HI2, 0, RBW, BRF, LINEARBLEND);
      }
      break;
    case 2:
      {
        fill_palette( leds_CH2, NUM_LEDS, HI2, 0, RBW, BRF, LINEARBLEND);
      }
      break;
    case 3:
      {
        fill_palette( leds_CH3, NUM_LEDS, HI2, 0, RBW, BRF, LINEARBLEND);
      }
      break;
  }
  FastLED.show();
  delay(wait);
}

//============================================================ FOR RAINBOW2 =============================================================
void Rainbow2(byte BRF, byte ch, int wait)
{
  static byte HI;
  HI = HI + 2;
  BRF = BRF * 2.55;
  //Serial.println(heatindex);
  switch (ch)
  {
    case 1:
      {
        fill_palette( leds_CH1, NUM_LEDS, HI, 20, RBW, BRF, LINEARBLEND);
      }
      break;
    case 2:
      {
        fill_palette( leds_CH2, NUM_LEDS, HI, 20, RBW, BRF, LINEARBLEND);
      }
      break;
    case 3:
      {
        fill_palette( leds_CH3, NUM_LEDS, HI, 20, RBW, BRF, LINEARBLEND);
      }
      break;
  }
  FastLED.show();
  delay(wait);
}


//============================================================ FOR AUTO COLOR =============================================================

void Temp_clr(int col_Temp)
{
  uint8_t heatindex;
  heatindex = map(col_Temp, 0, 70, 0, 255);
  for (int j = 0; j < NUM_LEDS; j++)
  {
    leds_CH1[j] = ColorFromPalette( myPal, heatindex); // normal palette access
    leds_CH2[j] = ColorFromPalette( myPal, heatindex); // normal palette access
    leds_CH3[j] = ColorFromPalette( myPal, heatindex); // normal palette access
  }
  FastLED.show();
}
//============================================================ FOR OFF =============================================================
void offline(byte ch)
{
  switch (ch)
  {
    case 1:
      {
        fill_solid( leds_CH1, NUM_LEDS, CRGB(0, 0, 0));
      }
      break;
    case 2:
      {
        fill_solid( leds_CH2, NUM_LEDS, CRGB(0, 0, 0));
      }
      break;
    case 3:
      {
        fill_solid( leds_CH3, NUM_LEDS, CRGB(0, 0, 0));
      }
      break;
  }
  FastLED.show();
}
//============================================SERVO FUNCTIONS====================================================================
void srvo()
{
  if (flag_on == 0)         //  One time flag
  {
    if (sys_stat2 == 1)  // sys. On flag
    {
      myservo.attach(sv1);
      //for (pos = 30; pos <= 90; pos += 1)
      for (pos = 90; pos >= 30; pos -= 1)
      {
        myservo.write(pos);
        delay(15);
      }

      // myservo.write(30);  //open
      flag_on = 1;
      delay(1000);
    }
  }

  else if (flag_on == 1)
  {
    myservo.detach();
  }

  if (flag_off == 0)
  {
    if (sys_stat2 == 0)
    {
      myservo.attach(sv1);
      //for (pos = 90; pos >= 30; pos -= 1)
      for (pos = 30; pos <= 90; pos += 1)
      {
        myservo.write(pos);
        delay(15);
      }
      //     myservo.write(90);  //close
      flag_off = 1;
      delay(1000);
    }
  }
  else if (flag_off == 1)
  {
    myservo.detach();
    if (sys_stat2 == 0 && flag_on == 1 && flag_off == 1)
    {
      flag_off = 0;
      flag_on = 0;
    }
  }
}

void srvo_auto()
{
  Res_Temp = constrain(Res_Temp, 0, 70);
  pos_auto = map(Res_Temp, 0, 70, 90, 30);
  pos_auto = constrain(pos_auto, 30, 90);
  if (pos_auto >= 60)
  {
    myservo.detach();
  }
  else
  {
    myservo.attach(sv1);
    myservo.write(pos_auto);
  }
  //Serial.println(pos_auto);

}
//=====================================================================================================================================

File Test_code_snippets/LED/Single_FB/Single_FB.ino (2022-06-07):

#include <Adafruit_NeoPixel.h>
//===============================  PIN MAPPING ======================================================

#define BACK_LED    A0    // Digital IO pin connected to the NeoPixels.

#define PIXEL_COUNT 8
//#define PIXEL_COUNT2 16
Adafruit_NeoPixel stripR = Adafruit_NeoPixel(PIXEL_COUNT, BACK_LED, NEO_GRB + NEO_KHZ800);

//=================FOR Single/Moving mode=========================

// Back====
uint32_t blueR = stripR.Color(0, 0, 255);
uint32_t cyanR = stripR.Color(0, 255, 255);
uint32_t darkBlueR = stripR.Color(0, 128, 255);
uint32_t greenR = stripR.Color(0, 255, 0);
uint32_t lightBlueR = stripR.Color(0, 191, 255);
uint32_t lightGreenR = stripR.Color(64, 255, 0);
uint32_t magentaR = stripR.Color(255, 0, 255);
uint32_t maroonR = stripR.Color(255, 0, 64);
uint32_t orangeR = stripR.Color(255, 128, 0);
uint32_t parrotGreenR = stripR.Color(191, 255, 0);
uint32_t pinkR = stripR.Color(255, 0, 191);
uint32_t purpleR = stripR.Color(128, 0, 255);
uint32_t redR = stripR.Color(255, 0, 0);
uint32_t violetR = stripR.Color(191, 0, 255);
uint32_t whiteR = stripR.Color(255, 255, 255);
uint32_t yellowR = stripR.Color(255, 255, 0);

//== led==

int delR;

int CR;

int BRR;



void setup()
{

  Serial.begin(9600);
  stripR.begin();
  stripR.show(); // Initialize all pixels to 'off'
}

void loop()
{
  delR = 50;

  CR = 1;

  BRR = 20;


  SingleR();

  //=====================================================================================================================================
  //Serial.println("End of loop");
}


//=========================================================== LED =================================================================

void SingleR()
{
  int BRR2 = BRR * 2.55;
  stripR.setBrightness(BRR2);

  uint32_t col;
  switch (CR) {
    case 1: col = blueR;
      break;
    case 2: col = cyanR;
      break;
    case 3: col = darkBlueR;
      break;
    case 4: col = greenR;
      break;
    case 5: col = lightBlueR;
      break;
    case 6: col = lightGreenR;
      break;
    case 7: col = magentaR;
      break;
    case 8: col = maroonR;
      break;
    case 9: col = orangeR;
      break;
    case 10: col = parrotGreenR;
      break;
    case 11: col = pinkR;
      break;
    case 12: col = purpleR;
      break;
    case 13: col = redR;
      break;
    case 14: col = violetR;
      break;
    case 15: col = whiteR;
      break;
    case 16: col = yellowR;
      break;
  }

  colorWipeR(col, delR);
}
//======================= For Single Mode==================================
void colorWipeR(uint32_t c, uint8_t wait)
{

  for (uint16_t i = 0; i < stripR.numPixels(); i++)
  {
    stripR.setPixelColor(i, c);
    stripR.show();
    delay(wait);
  }
}

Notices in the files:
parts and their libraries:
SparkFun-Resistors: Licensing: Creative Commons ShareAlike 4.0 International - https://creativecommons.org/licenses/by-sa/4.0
